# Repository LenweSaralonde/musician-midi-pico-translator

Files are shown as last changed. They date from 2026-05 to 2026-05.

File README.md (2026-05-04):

# Musician MIDI Pico Translator

DIY plug and play MIDI to USB translator interface for the [Musician MIDI](https://github.com/LenweSaralonde/MusicianMIDI) World of Warcraft add-on, based on a [Raspberry Pi Pico](https://www.raspberrypi.com/products/raspberry-pi-pico/).

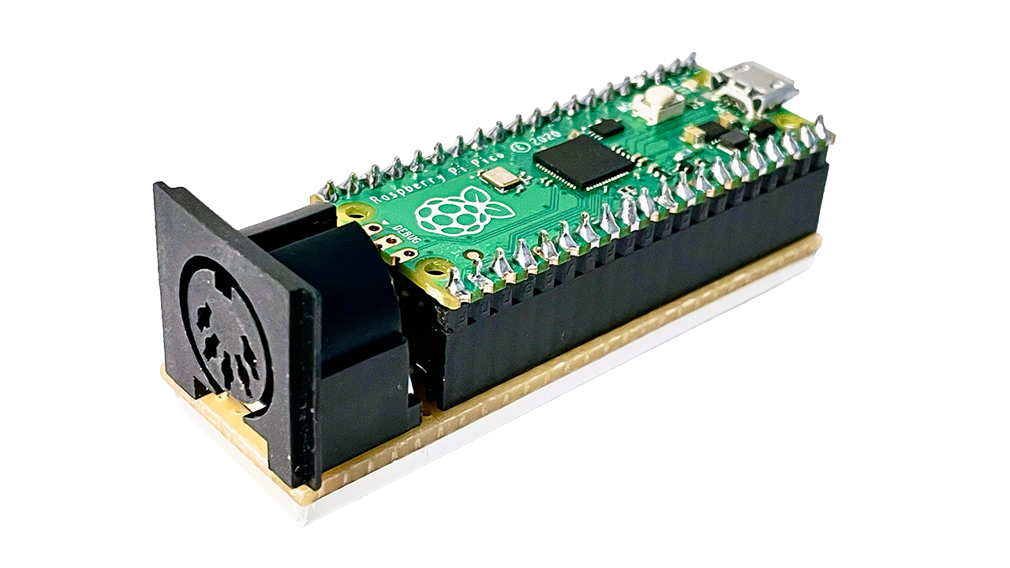
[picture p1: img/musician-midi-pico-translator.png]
Musician MIDI Pico Translator


## Table of contents

* [Specifications and features](#specifications)
* [How to use](#how-to-use)
* [Schematic](#schematic)
* [How to build and parts list](#how-to-build)
* [How to flash the Raspberry Pi Pico](#how-to-flash-the-raspberry-pi-pico)
  * [1. Download and install Arduino IDE](#1-download-and-install-arduino-ide)
  * [2. Add the Raspberry Pi Pico board package](#2-add-the-raspberry-pi-pico-board-package)
  * [3. Select the correct board and settings](#3-select-the-correct-board-and-settings)
  * [4. Open the sketch](#4-open-the-sketch)
  * [5. Connect the Pico in bootloader mode](#5-connect-the-pico-in-bootloader-mode)
  * [6. Upload the sketch](#6-upload-the-sketch)
  * [Update the software](#update-the-software)

## Specifications

The device consists of:
* A HID keyboard that translates incoming MIDI messages into keystrokes for the [Musician MIDI](https://github.com/LenweSaralonde/MusicianMIDI) add-on running in World of Warcraft.
* A standard MIDI to USB interface that can be used simultaneously with any software synthesizer or music production software to mitigate the audio latency problem in World of Warcraft.

### Features
* Compatible with all operating systems (Windows, macOS, Linux…).
* Plug and play (no driver required).
* Supports the QWERTY, AZERTY and QWERTZ keyboard layouts.
* N-Key rollover (all keys can play at the same time).
* Minimalistic design for low-cost and easy building using basic off-the-shelf components and tools.

## How to use

Connect the 5-pin DIN jack to your controller MIDI OUT and the USB to your computer.

Press the **onboard button** to choose the desired keyboard mode. The onboard LED will then blink according to the chosen mode:
1. **QWERTY** &ndash; 1 long and 1 short blinks
2. **AZERTY** &ndash; 1 long and 2 short blinks
3. **QWERTZ** &ndash; 1 long and 3 short blinks
4. **Disabled** &ndash; 1 long blink

The selected mode is saved when the device is disconnected. The onboard LED indicates which mode is active on power on, then it monitors the incoming MIDI messages.

## Schematic

The circuit is a minimalistic MIDI IN shield for the Raspberry Pi Pico.

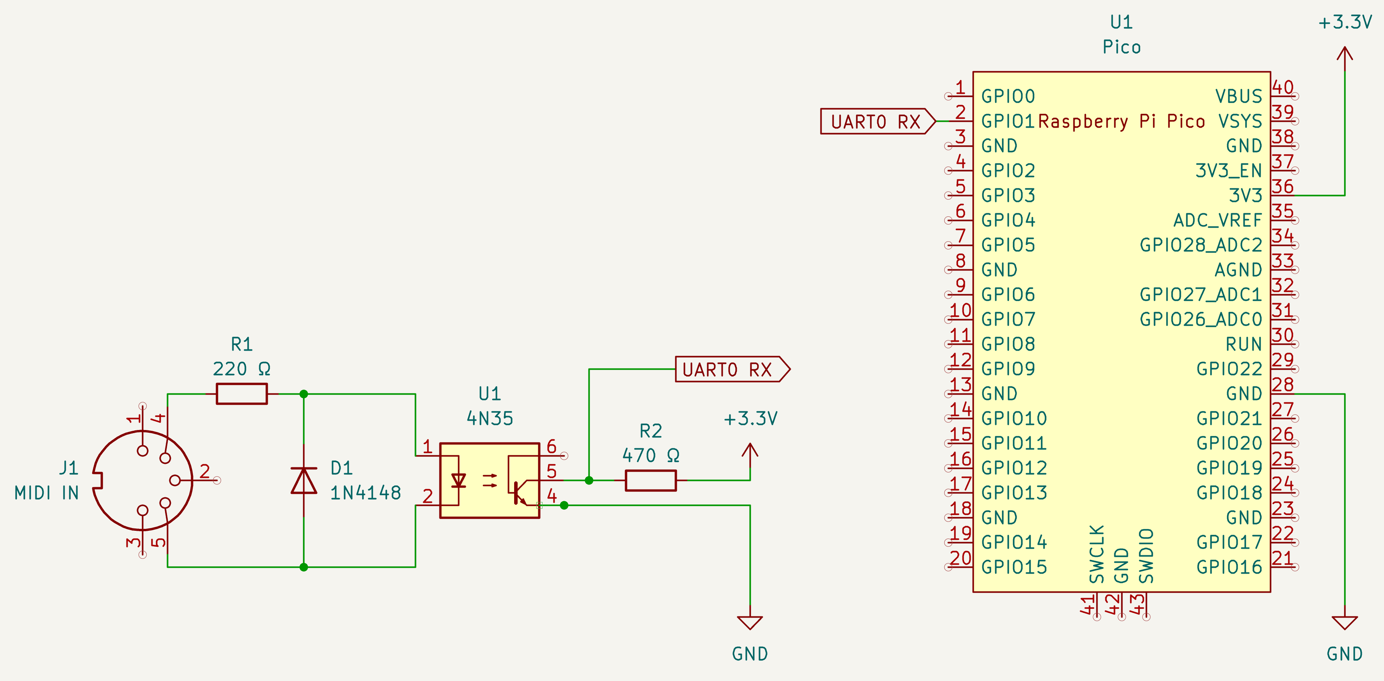
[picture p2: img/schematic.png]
Raspberry Pi Pico MIDI shield


It's built around the 4N35 optocoupler and is designed according to the MIDI specifications to limit potential damage to your gear in case of incorrect connection.

Any other MIDI shield design works, as long as it's compatible with the Raspberry Pi Pico and routes the MIDI IN to the Pico `UART0 RX` pin (2).

## How to build

The simplest solution is to build the circuit on a perfboard.

The components are placed under the Raspberry Pi to reduce the device footprint.

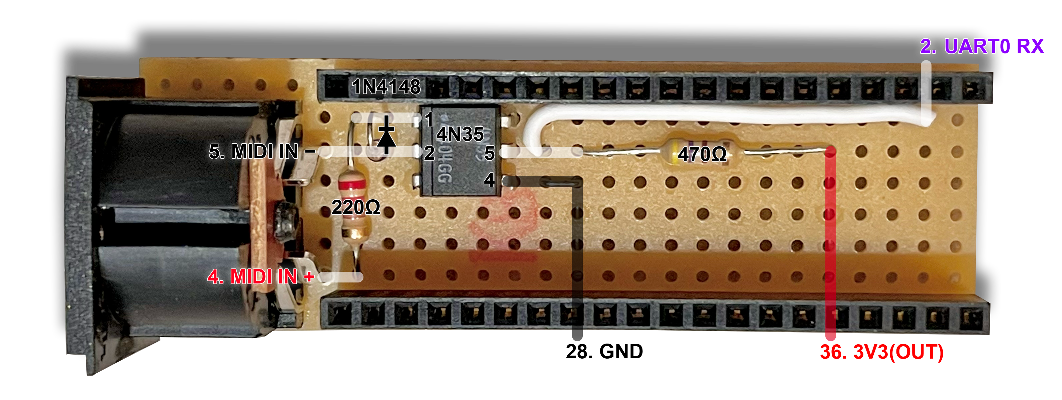
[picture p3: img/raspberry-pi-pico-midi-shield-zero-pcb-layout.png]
Raspberry Pi Pico MIDI shield zero PCB layout


Parts list:
* 1x Raspberry Pi Pico H (with pins)
* 1x 67 x 21 mm (26 x 8 holes) Single-sided zero PCB / perfboard
* 2x 20-way header sockets
* 1x 180° DIN socket
* 1x 4N35 optocoupler
* 1x 1N4148 diode
* 1x 220 Ω resistor
* 1x 470 Ω resistor
* Wire

The DIN socket legs may be too large to fit in the perfboard holes; don't hesitate to enlarge the holes with a mini drill.

The diode is mounted vertically with its ring (negative) side on top.

Insert the Raspberry Pi Pico with the USB port in the opposite direction of the DIN socket.

Once completed, glue the circuit on a piece of wood or plastic like an offcut of cable trunking to prevent the solder points from scratching your equipment. Add rubber feet to prevent it from moving.

> 💡 If you don't want to build the MIDI shield yourself, you can buy some that are already assembled, tested and ready to be flashed:
> * [Midimuso Pico MIDI full kit with Raspberry Pi Pico](https://midimuso.co.uk/index.php/product/pico-midi-built-including-pi-pico-board/) — £35

## How to flash the Raspberry Pi Pico

### 1. Download and install Arduino IDE

1. Go to **https://www.arduino.cc/en/software**
2. Select your operating system (it should be already selected) then click the **Download** button.
3. Open the downloaded file and follow the installer.
4. Launch **Arduino IDE**.

### 2. Add the Raspberry Pi Pico board package

Arduino IDE doesn't know about the Pico out of the box. You need to tell it where to find the board files.

1. Open **Preferences**.
   - macOS: `Arduino IDE` menu → `Preferences`
   - Windows: `File` menu → `Preferences`
2. Find the field labelled **"Additional boards manager URLs"**.
3. Click the small icon to the right of that field (it looks like two overlapping windows).
4. A text box opens. Paste this URL on a new line:
   ```
   https://github.com/earlephilhower/arduino-pico/releases/download/global/package_rp2040_index.json
   ```
5. Click **OK** to close the text box, then **OK** again to close Preferences.
6. Go to **Tools → Board → Boards Manager**.
7. In the search box, type `RP2040`.
8. Find **"Raspberry Pi Pico/RP2040/RP2350"** by **Earle F. Philhower, III** — ⚠️ make sure it says his name, not "Arduino".
9. Click **Install** — this downloads about 250 MB and takes a few minutes.
10. When it finishes, close the Boards Manager.

### 3. Select the correct board and settings

1. Go to **Tools → Board → Raspberry Pi Pico/RP2040/RP2350**, then select **Raspberry Pi Pico** — it should be the first option.
2. Go to **Tools**, find the option that begins with **USB Stack:**, then choose **Adafruit TinyUSB**.

> ⚠️ **The USB Stack setting is critical.** If you don't see the USB Stack option in the Tools menu, you selected the wrong board package (Arduino's instead of Earle's). Go back to Step 2 and make sure you installed the correct one.

### 4. Open the sketch

1. Go to **File → Open**.
2. Navigate to and select `musician-midi-pico-translator.ino`.
3. The sketch opens in the editor — you should see code starting with a large comment block.

### 5. Connect the Pico in bootloader mode

1. **Hold down the BOOTSEL button** — the small white button on the Pico board.
2. While still holding it, **plug the USB cable in**.
3. **Release the button**.

The Pico now appears as a USB drive called **RPI-RP2** on your desktop (like a flash drive). This confirms it's ready to receive the program.

> ⚠️ If you don't see the RPI-RP2 drive, your USB cable is charge-only and has no data wires. Try a different cable.

### 6. Upload the sketch

1. In Arduino IDE, go to **Tools → Port** and select the port that mentions **UF2 Board** or **RPI-RP2**.
2. Click the **Upload button** — the right-pointing arrow `→` in the top-left toolbar.
3. Arduino IDE will:
   - Compile the code (bottom panel shows progress — takes 30–60 seconds the first time).
   - Copy the compiled file onto the Pico automatically.
4. The RPI-RP2 drive disappears from your desktop — **this is normal and means it worked**. On macOS, you may get a warning notification that says the drive was not ejected properly — you can safely dismiss it.
5. Wait for the **Done uploading** message in Arduino IDE.
6. The translator is now operational.

> ℹ️ On macOS, a configuration window may appear the first time, inviting you to configure your "Generic" keyboard. It's not required and you can just click "Quit" to close the window.

### Update the software

To update the Raspberry Pi Pico software, just launch Arduino IDE, then repeat from step 3.

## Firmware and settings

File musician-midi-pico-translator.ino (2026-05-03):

/**
 * Musician MIDI Pico Translator — USB Composite Device
 * - Standard USB MIDI (UART → USB byte-level thru)
 * - HID Keyboard with NKRO (N-Key Rollover)
 * - Mode persisted in EEPROM (flash emulation)
 * - LED mode animation and MIDI activity monitor
 *
 * Requirements:
 *   Board: Raspberry Pi Pico/RP2040 by Earle Philhower
 *   USB Stack: Adafruit TinyUSB
 *   Port: UF2_Board
 *
 * MIDI IN wiring (4N35 optocoupler):
 *   MIDI DIN-5 pin 4 ──[220Ω]──→ pin 1 (Anode)
 *   MIDI DIN-5 pin 5 ──────────→ pin 2 (Cathode)
 *                                pin 4 (Emitter)   → GND
 *                                pin 5 (Collector) → GP1 + 470Ω pull-up to 3.3V
 *
 * Declaration order (strict — Arduino preprocessor cannot forward-declare
 * functions that take enum/struct parameters):
 *
 *  1. Includes
 *  2. HID descriptor + USB objects
 *  3. enum Mode          ← used by animStart, modeSave, btnUpdate
 *  4. enum Key + tables  ← used by hidForKey, hidDispatch
 *  5. hidForKey()        ← uses Key, Mode
 *  6. USB MIDI ring      ← used by thruByte, ringDrain
 *  7. UART ISR + init
 *  8. NKRO key state
 *  9. LED (animStart uses Mode — must come after enum Mode)
 * 10. MIDI helpers
 * 11. EEPROM (uses Mode)
 * 12. Thru pipeline
 * 13. HID pipeline       ← uses hidForKey, holdKey, etc.
 * 14. BOOTSEL button     ← uses animStart, Mode, modeSave
 * 15. setup / loop
 */

// ─────────────────────────────────────────────────────────────────────────────
// 1. Includes
// ─────────────────────────────────────────────────────────────────────────────

#include <Arduino.h>
#include <Adafruit_TinyUSB.h>
#include <EEPROM.h>
#include <hardware/uart.h>
#include <hardware/irq.h>
#include <hardware/gpio.h>

// ─────────────────────────────────────────────────────────────────────────────
// 2. HID descriptor + USB objects
// ─────────────────────────────────────────────────────────────────────────────

#define USB_VENDOR_ID     0x1209 // pid.codes open source vendor
#define USB_VENDOR_NAME   "Generic"

#define USB_PRODUCT_ID    0xBA55 // 🎸
#define USB_PRODUCT_NAME  "Musician MIDI Pico Translator"

#define REPORT_ID_NKRO    1
#define NKRO_BITMAP_BYTES 16

static const uint8_t hid_desc[] = {
  HID_USAGE_PAGE(HID_USAGE_PAGE_DESKTOP),
  HID_USAGE(HID_USAGE_DESKTOP_KEYBOARD),
  HID_COLLECTION(HID_COLLECTION_APPLICATION),
    HID_REPORT_ID(REPORT_ID_NKRO)
    HID_USAGE_PAGE(HID_USAGE_PAGE_KEYBOARD),
    HID_USAGE_MIN(224), HID_USAGE_MAX(231),
    HID_LOGICAL_MIN(0), HID_LOGICAL_MAX(1),
    HID_REPORT_COUNT(8), HID_REPORT_SIZE(1),
    HID_INPUT(HID_DATA | HID_VARIABLE | HID_ABSOLUTE),
    HID_USAGE_PAGE(HID_USAGE_PAGE_KEYBOARD),
    HID_USAGE_MIN(0), HID_USAGE_MAX(127),
    HID_LOGICAL_MIN(0), HID_LOGICAL_MAX(1),
    HID_REPORT_COUNT(128), HID_REPORT_SIZE(1),
    HID_INPUT(HID_DATA | HID_VARIABLE | HID_ABSOLUTE),
  HID_COLLECTION_END
};

struct __attribute__((packed)) NKROReport {
  uint8_t modifier;
  uint8_t bitmap[NKRO_BITMAP_BYTES];
};
static NKROReport nkroReport = {};

Adafruit_USBD_HID  usb_hid(hid_desc, sizeof(hid_desc),
                            HID_ITF_PROTOCOL_NONE, 1, false);
Adafruit_USBD_MIDI usb_midi;

// ─────────────────────────────────────────────────────────────────────────────
// 3. enum Mode
// ─────────────────────────────────────────────────────────────────────────────

enum Mode : uint8_t { QWERTY=1, AZERTY=2, QWERTZ=3, DISABLED=4 };
static Mode currentMode = DISABLED;

// ─────────────────────────────────────────────────────────────────────────────
// 4. enum Key + note/layout tables
// ─────────────────────────────────────────────────────────────────────────────

#define NOTE_MIN   28
#define NOTE_MAX  103
#define NOTE_COUNT 76

enum Key : uint8_t {
  K_ENTER=0,K_DELETE,K_ESCAPE,K_BACKSPACE,K_TAB,
  K_NPDEC,K_NPADD,K_NPSUB,K_NPMUL,K_NPDIV,
  K_NP0,K_NP1,K_NP2,K_NP3,K_NP4,K_NP5,K_NP6,K_NP7,K_NP8,K_NP9,
  K_A,K_B,K_C,K_D,K_E,K_F,K_G,K_H,K_I,K_J,
  K_K,K_L,K_M,K_N,K_O,K_P,K_Q,K_R,K_S,K_T,
  K_U,K_V,K_W,K_X,K_Y,K_Z,
  K_1,K_2,K_3,K_4,K_5,K_6,K_7,K_8,K_9,K_0,
  K_F1,K_F2,K_F3,K_F4,K_F5,K_F6,K_F7,K_F8,K_F9,K_F10,K_F11,K_F12,
  K_HOME,K_END,K_PGDN,K_PGUP,
  K_LEFT,K_UP,K_RIGHT,K_DOWN,
  K_COUNT
};

static const Key noteToKey[NOTE_COUNT] = {
  K_ENTER,K_DELETE,K_ESCAPE,K_BACKSPACE,K_TAB,
  K_NPDEC,K_NPADD,K_NPSUB,K_NPMUL,K_NPDIV,
  K_NP0,K_NP1,K_NP2,K_NP3,K_NP4,K_NP5,K_NP6,K_NP7,K_NP8,K_NP9,
  K_A,K_B,K_C,K_D,K_E,K_F,K_G,K_H,K_I,K_J,
  K_K,K_L,K_M,K_N,K_O,K_P,K_Q,K_R,K_S,K_T,
  K_U,K_V,K_W,K_X,K_Y,K_Z,
  K_1,K_2,K_3,K_4,K_5,K_6,K_7,K_8,K_9,K_0,
  K_F1,K_F2,K_F3,K_F4,K_F5,K_F6,K_F7,K_F8,K_F9,K_F10,K_F11,K_F12,
  K_HOME,K_END,K_PGDN,K_PGUP,
  K_LEFT,K_UP,K_RIGHT,K_DOWN,
};

static const uint8_t layoutQWERTY[K_COUNT] = {
  HID_KEY_ENTER,HID_KEY_DELETE,HID_KEY_ESCAPE,HID_KEY_BACKSPACE,HID_KEY_TAB,
  HID_KEY_KEYPAD_DECIMAL,HID_KEY_KEYPAD_ADD,HID_KEY_KEYPAD_SUBTRACT,
  HID_KEY_KEYPAD_MULTIPLY,HID_KEY_KEYPAD_DIVIDE,
  HID_KEY_KEYPAD_0,HID_KEY_KEYPAD_1,HID_KEY_KEYPAD_2,HID_KEY_KEYPAD_3,HID_KEY_KEYPAD_4,
  HID_KEY_KEYPAD_5,HID_KEY_KEYPAD_6,HID_KEY_KEYPAD_7,HID_KEY_KEYPAD_8,HID_KEY_KEYPAD_9,
  HID_KEY_A,HID_KEY_B,HID_KEY_C,HID_KEY_D,HID_KEY_E,HID_KEY_F,HID_KEY_G,
  HID_KEY_H,HID_KEY_I,HID_KEY_J,HID_KEY_K,HID_KEY_L,HID_KEY_M,HID_KEY_N,
  HID_KEY_O,HID_KEY_P,HID_KEY_Q,HID_KEY_R,HID_KEY_S,HID_KEY_T,HID_KEY_U,
  HID_KEY_V,HID_KEY_W,HID_KEY_X,HID_KEY_Y,HID_KEY_Z,
  HID_KEY_1,HID_KEY_2,HID_KEY_3,HID_KEY_4,HID_KEY_5,
  HID_KEY_6,HID_KEY_7,HID_KEY_8,HID_KEY_9,HID_KEY_0,
  HID_KEY_F1,HID_KEY_F2,HID_KEY_F3,HID_KEY_F4,HID_KEY_F5,HID_KEY_F6,
  HID_KEY_F7,HID_KEY_F8,HID_KEY_F9,HID_KEY_F10,HID_KEY_F11,HID_KEY_F12,
  HID_KEY_HOME,HID_KEY_END,HID_KEY_PAGE_DOWN,HID_KEY_PAGE_UP,
  HID_KEY_ARROW_LEFT,HID_KEY_ARROW_UP,HID_KEY_ARROW_RIGHT,HID_KEY_ARROW_DOWN,
};

static const uint8_t layoutAZERTY[K_COUNT] = {
  HID_KEY_ENTER,HID_KEY_DELETE,HID_KEY_ESCAPE,HID_KEY_BACKSPACE,HID_KEY_TAB,
  HID_KEY_KEYPAD_DECIMAL,HID_KEY_KEYPAD_ADD,HID_KEY_KEYPAD_SUBTRACT,
  HID_KEY_KEYPAD_MULTIPLY,HID_KEY_KEYPAD_DIVIDE,
  HID_KEY_KEYPAD_0,HID_KEY_KEYPAD_1,HID_KEY_KEYPAD_2,HID_KEY_KEYPAD_3,HID_KEY_KEYPAD_4,
  HID_KEY_KEYPAD_5,HID_KEY_KEYPAD_6,HID_KEY_KEYPAD_7,HID_KEY_KEYPAD_8,HID_KEY_KEYPAD_9,
  HID_KEY_Q,         // A → physical Q on AZERTY
  HID_KEY_B,HID_KEY_C,HID_KEY_D,HID_KEY_E,HID_KEY_F,HID_KEY_G,
  HID_KEY_H,HID_KEY_I,HID_KEY_J,HID_KEY_K,HID_KEY_L,
  HID_KEY_SEMICOLON, // M → physical ; on AZERTY
  HID_KEY_N,HID_KEY_O,HID_KEY_P,
  HID_KEY_A,         // Q → physical A on AZERTY
  HID_KEY_R,HID_KEY_S,HID_KEY_T,HID_KEY_U,HID_KEY_V,
  HID_KEY_Z,         // W → physical Z on AZERTY
  HID_KEY_X,HID_KEY_Y,
  HID_KEY_W,         // Z → physical W on AZERTY
  HID_KEY_1,HID_KEY_2,HID_KEY_3,HID_KEY_4,HID_KEY_5,
  HID_KEY_6,HID_KEY_7,HID_KEY_8,HID_KEY_9,HID_KEY_0,
  HID_KEY_F1,HID_KEY_F2,HID_KEY_F3,HID_KEY_F4,HID_KEY_F5,HID_KEY_F6,
  HID_KEY_F7,HID_KEY_F8,HID_KEY_F9,HID_KEY_F10,HID_KEY_F11,HID_KEY_F12,
  HID_KEY_HOME,HID_KEY_END,HID_KEY_PAGE_DOWN,HID_KEY_PAGE_UP,
  HID_KEY_ARROW_LEFT,HID_KEY_ARROW_UP,HID_KEY_ARROW_RIGHT,HID_KEY_ARROW_DOWN,
};

static const uint8_t layoutQWERTZ[K_COUNT] = {
  HID_KEY_ENTER,HID_KEY_DELETE,HID_KEY_ESCAPE,HID_KEY_BACKSPACE,HID_KEY_TAB,
  HID_KEY_KEYPAD_DECIMAL,HID_KEY_KEYPAD_ADD,HID_KEY_KEYPAD_SUBTRACT,
  HID_KEY_KEYPAD_MULTIPLY,HID_KEY_KEYPAD_DIVIDE,
  HID_KEY_KEYPAD_0,HID_KEY_KEYPAD_1,HID_KEY_KEYPAD_2,HID_KEY_KEYPAD_3,HID_KEY_KEYPAD_4,
  HID_KEY_KEYPAD_5,HID_KEY_KEYPAD_6,HID_KEY_KEYPAD_7,HID_KEY_KEYPAD_8,HID_KEY_KEYPAD_9,
  HID_KEY_A,HID_KEY_B,HID_KEY_C,HID_KEY_D,HID_KEY_E,HID_KEY_F,HID_KEY_G,
  HID_KEY_H,HID_KEY_I,HID_KEY_J,HID_KEY_K,HID_KEY_L,HID_KEY_M,HID_KEY_N,
  HID_KEY_O,HID_KEY_P,HID_KEY_Q,HID_KEY_R,HID_KEY_S,HID_KEY_T,HID_KEY_U,
  HID_KEY_V,HID_KEY_W,HID_KEY_X,
  HID_KEY_Z,HID_KEY_Y, // Y↔Z swapped on QWERTZ
  HID_KEY_1,HID_KEY_2,HID_KEY_3,HID_KEY_4,HID_KEY_5,
  HID_KEY_6,HID_KEY_7,HID_KEY_8,HID_KEY_9,HID_KEY_0,
  HID_KEY_F1,HID_KEY_F2,HID_KEY_F3,HID_KEY_F4,HID_KEY_F5,HID_KEY_F6,
  HID_KEY_F7,HID_KEY_F8,HID_KEY_F9,HID_KEY_F10,HID_KEY_F11,HID_KEY_F12,
  HID_KEY_HOME,HID_KEY_END,HID_KEY_PAGE_DOWN,HID_KEY_PAGE_UP,
  HID_KEY_ARROW_LEFT,HID_KEY_ARROW_UP,HID_KEY_ARROW_RIGHT,HID_KEY_ARROW_DOWN,
};

// ─────────────────────────────────────────────────────────────────────────────
// 5. hidForKey()  — needs Key and Mode, both now declared above
// ─────────────────────────────────────────────────────────────────────────────

static uint8_t hidForKey(Key k) {
  switch (currentMode) {
    case QWERTY: return layoutQWERTY[k];
    case AZERTY: return layoutAZERTY[k];
    case QWERTZ: return layoutQWERTZ[k];
    default:     return 0;
  }
}

// ─────────────────────────────────────────────────────────────────────────────
// 6. USB MIDI ring buffer  — used by thruByte
// ─────────────────────────────────────────────────────────────────────────────

#define RING_SIZE 128
static uint8_t ring[RING_SIZE][4];
static uint8_t ringHead  = 0;
static uint8_t ringTail  = 0;
static uint8_t ringCount = 0;

static void ringPush(uint8_t cin, uint8_t b0, uint8_t b1, uint8_t b2) {
  if (ringCount >= RING_SIZE) return;
  ring[ringHead][0] = cin; ring[ringHead][1] = b0;
  ring[ringHead][2] = b1;  ring[ringHead][3] = b2;
  ringHead  = (ringHead + 1) & (RING_SIZE - 1);
  ringCount++;
}

static void ringDrain() {
  if (!TinyUSBDevice.mounted()) {
    ringHead = ringTail = ringCount = 0; return;
  }
  while (ringCount > 0) {
    if (tud_midi_n_stream_write(0, 0, ring[ringTail], 4) == 0) break;
    ringTail  = (ringTail + 1) & (RING_SIZE - 1);
    ringCount--;
  }
  if (ringCount == 0) usb_midi.flush();
}

// ─────────────────────────────────────────────────────────────────────────────
// 7. Interrupt-driven UART RX
// ─────────────────────────────────────────────────────────────────────────────

#define MIDI_UART_HW  uart0
#define MIDI_BAUD     31250
#define SW_FIFO_SIZE  256

static uint8_t           swFifo[SW_FIFO_SIZE];
static volatile uint16_t swHead = 0;
static volatile uint16_t swTail = 0;

static inline bool swEmpty() { return swHead == swTail; }

static void uartRxISR() {
  while (uart_is_readable(MIDI_UART_HW)) {
    uint8_t b     = (uint8_t)uart_getc(MIDI_UART_HW);
    uint16_t next = (swHead + 1) & (SW_FIFO_SIZE - 1);
    if (next != swTail) { swFifo[swHead] = b; swHead = next; }
  }
}

static void uartInit() {
  uart_init(MIDI_UART_HW, MIDI_BAUD);
  gpio_set_function(1, GPIO_FUNC_UART);
  gpio_set_function(0, GPIO_FUNC_UART);
  uart_set_hw_flow(MIDI_UART_HW, false, false);
  uart_set_format(MIDI_UART_HW, 8, 1, UART_PARITY_NONE);
  uart_set_fifo_enabled(MIDI_UART_HW, true);
  irq_set_exclusive_handler(UART0_IRQ, uartRxISR);
  irq_set_enabled(UART0_IRQ, true);
  uart_set_irq_enables(MIDI_UART_HW, true, false);
}

// ─────────────────────────────────────────────────────────────────────────────
// 8. NKRO HID key state
// ─────────────────────────────────────────────────────────────────────────────

static bool reportDirty = false;

static void sendHIDReport() {
  if (!usb_hid.ready()) return;
  usb_hid.sendReport(REPORT_ID_NKRO, &nkroReport, sizeof(nkroReport));
  reportDirty = false;
}

static void bitmapSet(uint8_t kc) {
  if (kc >= 224 && kc <= 231)  nkroReport.modifier        |=  (1 << (kc - 224));
  else if (kc > 0 && kc < 128) nkroReport.bitmap[kc >> 3] |=  (1 << (kc & 7));
}
static void bitmapClear(uint8_t kc) {
  if (kc >= 224 && kc <= 231)  nkroReport.modifier        &= ~(1 << (kc - 224));
  else if (kc > 0 && kc < 128) nkroReport.bitmap[kc >> 3] &= ~(1 << (kc & 7));
}

static void holdKey(uint8_t kc)    { if (!kc) return; bitmapSet(kc);   reportDirty = true; }
static void releaseKey(uint8_t kc) { if (!kc) return; bitmapClear(kc); reportDirty = true; }
static void releaseAllKeys() {
  memset(&nkroReport, 0, sizeof(nkroReport));
  reportDirty = true;
  uint32_t t = millis();
  while (!usb_hid.ready() && millis() - t < 20) yield();
  sendHIDReport();
}
static void holdSpace()            { bitmapSet(HID_KEY_SPACE);   reportDirty = true; }
static void releaseSpace()         { bitmapClear(HID_KEY_SPACE); reportDirty = true; }

// ─────────────────────────────────────────────────────────────────────────────
// 9. LED  — animStart(Mode) now safe: Mode declared at step 3
// ─────────────────────────────────────────────────────────────────────────────

#define LONG_MS  500u
#define SHORT_MS 120u
#define GAP_MS   700u

struct Pulse { uint16_t onMs; uint16_t offMs; };
static const Pulse anim1[] = { {LONG_MS,SHORT_MS},{SHORT_MS,GAP_MS} };
static const Pulse anim2[] = { {LONG_MS,SHORT_MS},{SHORT_MS,SHORT_MS},{SHORT_MS,GAP_MS} };
static const Pulse anim3[] = { {LONG_MS,SHORT_MS},{SHORT_MS,SHORT_MS},{SHORT_MS,SHORT_MS},{SHORT_MS,GAP_MS} };
static const Pulse anim4[] = { {LONG_MS,GAP_MS} };

struct AnimDef { const Pulse *p; uint8_t n; };
static const AnimDef anims[5] = {
  {nullptr,0},
  {anim1, sizeof(anim1)/sizeof(anim1[0])},
  {anim2, sizeof(anim2)/sizeof(anim2[0])},
  {anim3, sizeof(anim3)/sizeof(anim3[0])},
  {anim4, sizeof(anim4)/sizeof(anim4[0])},
};

static bool     animRunning = false;
static uint8_t  animIdx     = 0;
static bool     animInOn    = false;
static uint32_t animUntil   = 0;

static void animStart(Mode m) {
  animRunning = true;
  animIdx     = 0;
  animInOn    = true;
  animUntil   = millis() + anims[m].p[0].onMs;
  digitalWrite(LED_BUILTIN, HIGH);
}

static void animUpdate() {
  if (!animRunning) return;
  if (millis() < animUntil) return;
  const AnimDef &def = anims[currentMode];
  if (animInOn) {
    animInOn  = false;
    animUntil = millis() + def.p[animIdx].offMs;
    digitalWrite(LED_BUILTIN, LOW);
  } else {
    if (++animIdx >= def.n) {
      animRunning = false;
      digitalWrite(LED_BUILTIN, LOW);
      return;
    }
    animInOn  = true;
    animUntil = millis() + def.p[animIdx].onMs;
    digitalWrite(LED_BUILTIN, HIGH);
  }
}

// MIDI activity monitor — only active when no animation is playing
#define MIDI_LED_MS   20u
static uint32_t midiLedOffAt = 0;

static void ledMidiActivity(uint8_t b) {
  if (animRunning) return;
  if (b >= 0xF8) return;  // ignore clock and all realtime messages
  digitalWrite(LED_BUILTIN, HIGH);
  midiLedOffAt = millis() + MIDI_LED_MS;
}

static void ledUpdate() {
  if (animRunning) return;
  if (midiLedOffAt && millis() >= midiLedOffAt) {
    digitalWrite(LED_BUILTIN, LOW);
    midiLedOffAt = 0;
  }
}

// ─────────────────────────────────────────────────────────────────────────────
// 10. MIDI helpers
// ─────────────────────────────────────────────────────────────────────────────

static uint8_t midiDataBytes(uint8_t status) {
  switch (status & 0xF0) {
    case 0x80: case 0x90: case 0xA0:
    case 0xB0: case 0xE0: return 2;
    case 0xC0: case 0xD0: return 1;
    case 0xF0:
      if (status == 0xF2) return 2;
      if (status == 0xF3) return 1;
      return 0;
    default: return 0;
  }
}

// ─────────────────────────────────────────────────────────────────────────────
// 11. EEPROM persistence  — uses Mode (declared at step 3)
// ─────────────────────────────────────────────────────────────────────────────

#define EEPROM_SIZE        4
#define EEPROM_MAGIC       0xA5
#define EEPROM_ADDR_MAGIC  0
#define EEPROM_ADDR_MODE   1

static void modeSave(uint8_t mode) {
  EEPROM.write(EEPROM_ADDR_MAGIC, EEPROM_MAGIC);
  EEPROM.write(EEPROM_ADDR_MODE,  mode);
  EEPROM.commit();
}

static uint8_t modeLoad() {
  EEPROM.begin(EEPROM_SIZE);
  if (EEPROM.read(EEPROM_ADDR_MAGIC) != EEPROM_MAGIC) return 4; // DISABLED
  uint8_t m = EEPROM.read(EEPROM_ADDR_MODE);
  if (m < 1 || m > 4) return 4;
  return m;
}

// ─────────────────────────────────────────────────────────────────────────────
// 12. Pipeline 1 — MIDI thru
// ─────────────────────────────────────────────────────────────────────────────

#define SYSEX_MAX 512u

static uint8_t  thru_status  = 0;
static uint8_t  thru_dExp    = 0;
static uint8_t  thru_d[2]    = {};
static uint8_t  thru_dLen    = 0;
static bool     thru_inSx    = false;
static uint8_t  thru_sx[3]   = {};
static uint8_t  thru_sxLen   = 0;
static uint16_t thru_sxTotal = 0;

static uint8_t thruCIN(uint8_t s) {
  switch (s & 0xF0) {
    case 0x80: return 0x08; case 0x90: return 0x09;
    case 0xA0: return 0x0A; case 0xB0: return 0x0B;
    case 0xC0: return 0x0C; case 0xD0: return 0x0D;
    case 0xE0: return 0x0E;
    case 0xF0:
      if (s == 0xF2) return 0x03;
      if (s == 0xF3) return 0x02;
      return 0x05;
    default: return 0x0F;
  }
}

static void thruSxFlush(bool end) {
  if (thru_sxLen == 0) { thru_inSx = false; return; }
  if (end) {
    ringPush((uint8_t)(0x04 + thru_sxLen),
             thru_sx[0],
             thru_sxLen > 1 ? thru_sx[1] : 0,
             thru_sxLen > 2 ? thru_sx[2] : 0);
    thru_sxLen = 0; thru_inSx = false; thru_sxTotal = 0;
  } else {
    ringPush(0x04, thru_sx[0], thru_sx[1], thru_sx[2]);
    thru_sxLen = 0;
  }
}

static void thruByte(uint8_t b) {
  if (b >= 0xF8) { ringPush(0x0F, b, 0, 0); return; }

  if (thru_inSx) {
    if (++thru_sxTotal > SYSEX_MAX) {
      thru_inSx = false; thru_sxLen = 0; thru_sxTotal = 0; thru_status = 0; return;
    }
    thru_sx[thru_sxLen++] = b;
    if (b == 0xF7 || thru_sxLen == 3) thruSxFlush(b == 0xF7);
    return;
  }

  if (b & 0x80) {
    if (b == 0xF0) {
      thru_inSx = true; thru_sxLen = 0; thru_sxTotal = 1;
      thru_sx[thru_sxLen++] = 0xF0; return;
    }
    if (b == 0xF7) return;
    thru_status = b; thru_dExp = midiDataBytes(b); thru_dLen = 0;
    if (thru_dExp == 0) {
      ringPush(thruCIN(b), b, 0, 0);
      if (b >= 0xF1) thru_status = 0;
    }
    return;
  }

  if (!thru_status) return;
  if (thru_dLen < 2) thru_d[thru_dLen] = b;
  thru_dLen++;
  if (thru_dLen == thru_dExp) {
    ringPush(thruCIN(thru_status), thru_status,
             thru_d[0], thru_dExp > 1 ? thru_d[1] : 0);
    thru_dLen = 0;
    if (thru_status >= 0xF1) thru_status = 0;
  }
}

// ─────────────────────────────────────────────────────────────────────────────
// 13. Pipeline 2 — HID parser  — hidForKey/holdKey/etc. all declared above
// ─────────────────────────────────────────────────────────────────────────────

static uint8_t  hid_status  = 0;
static uint8_t  hid_dExp    = 0;
static uint8_t  hid_d[2]    = {};
static uint8_t  hid_dLen    = 0;
static bool     hid_inSx    = false;
static uint16_t hid_sxTotal = 0;

static void hidDispatch() {
  if (currentMode == DISABLED) return;
  uint8_t type = hid_status & 0xF0;
  uint8_t d1   = hid_d[0];
  uint8_t d2   = hid_dLen > 1 ? hid_d[1] : 0;
  if (type == 0x90 && d2 > 0) {
    if (d1 >= NOTE_MIN && d1 <= NOTE_MAX)
      holdKey(hidForKey(noteToKey[d1 - NOTE_MIN]));
  } else if (type == 0x80 || (type == 0x90 && d2 == 0)) {
    if (d1 >= NOTE_MIN && d1 <= NOTE_MAX)
      releaseKey(hidForKey(noteToKey[d1 - NOTE_MIN]));
  } else if (type == 0xB0 && d1 == 64) {
    if (d2 >= 64) holdSpace(); else releaseSpace();
  }
}

static void hidByte(uint8_t b) {
  if (b >= 0xF8) return;
  if (hid_inSx) {
    if (++hid_sxTotal > SYSEX_MAX) {
      hid_inSx = false; hid_sxTotal = 0; hid_status = 0;
    } else if (b == 0xF7) hid_inSx = false;
    return;
  }
  if (b & 0x80) {
    if (b == 0xF0) { hid_inSx = true; hid_sxTotal = 1; return; }
    if (b == 0xF7) return;
    hid_status = b; hid_dExp = midiDataBytes(b); hid_dLen = 0;
    if (b >= 0xF1) hid_status = 0;
    return;
  }
  if (!hid_status) return;
  if (hid_dLen < 2) hid_d[hid_dLen] = b;
  hid_dLen++;
  if (hid_dLen == hid_dExp) {
    hidDispatch();
    hid_dLen = 0;
    if (hid_status >= 0xF1) hid_status = 0;
  }
}

// ─────────────────────────────────────────────────────────────────────────────
// 14. BOOTSEL button  — animStart/Mode/modeSave all declared above
// ─────────────────────────────────────────────────────────────────────────────

#define BOOTSEL_POLL_MS  5u
#define DEBOUNCE_MS     40u

static bool     btn_lastRaw  = false;
static bool     btn_state    = false;
static uint32_t btn_lastEdge = 0;

static void btnUpdate() {
  static uint32_t lastPoll = 0;
  uint32_t now = millis();
  if (now - lastPoll < BOOTSEL_POLL_MS) return;
  lastPoll = now;
  bool raw = rp2040.isPicoW() ? false : (bool)BOOTSEL;
  if (raw != btn_lastRaw) { btn_lastRaw = raw; btn_lastEdge = now; }
  if (now - btn_lastEdge < DEBOUNCE_MS) return;
  if (raw && !btn_state) {
    btn_state   = true;
    currentMode = (Mode)((currentMode % 4) + 1);
    releaseAllKeys();
    modeSave((uint8_t)currentMode);
    animStart(currentMode);
  } else if (!raw && btn_state) {
    btn_state = false;
  }
}

// ─────────────────────────────────────────────────────────────────────────────
// 15. Setup & loop
// ─────────────────────────────────────────────────────────────────────────────

void setup() {
  pinMode(LED_BUILTIN, OUTPUT);
  digitalWrite(LED_BUILTIN, LOW);

  currentMode = (Mode)modeLoad();

  TinyUSBDevice.setProductDescriptor(USB_PRODUCT_NAME);
  TinyUSBDevice.setManufacturerDescriptor(USB_VENDOR_NAME);
  TinyUSBDevice.setID(USB_VENDOR_ID, USB_PRODUCT_ID);

  usb_hid.setPollInterval(1);
  usb_hid.begin();
  usb_midi.begin();

  while (!TinyUSBDevice.mounted()) delay(1);
  delay(300);

  uartInit();

  animStart(currentMode);
  while (animRunning) { animUpdate(); yield(); }
}

void loop() {
  while (!swEmpty()) {
    irq_set_enabled(UART0_IRQ, false);
    uint8_t b = swFifo[swTail];
    swTail = (swTail + 1) & (SW_FIFO_SIZE - 1);
    irq_set_enabled(UART0_IRQ, true);
    thruByte(b);
    hidByte(b);
    ledMidiActivity(b);
  }
  if (reportDirty) sendHIDReport();
  ringDrain();
  btnUpdate();
  animUpdate();
  ledUpdate();
  yield();
}

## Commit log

2026-05-02 First version, full documentation
    [raspberry-pi-pico-midi-shield.kicad_sch]
2026-05-03 Forced poll rate to 1000 Hz
2026-05-03 Fixed dropped and doubled notes
    [musician-midi-pico-translator.ino]
